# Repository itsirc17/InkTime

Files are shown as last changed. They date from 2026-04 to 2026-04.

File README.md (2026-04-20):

# InkTime

Designed for optimal energy efficiency, InkTime is a custom e-paper smartwatch project. This document serves as a complete technical reference for the project.

## Block Diagram(Architecture)

```mermaid
graph TD
    %% Central MCU
    MCU[nRF52840 Microcontroller]

    %% Power Subsystem
    USB[USB-C Port] -->|5V VBUS| ESD[ESD Protection USBLC6]
    ESD -->|5V| CHG[BQ25180 LiPo Charger]
    DCDC -->|3.3V System Power| MCU
    DCDC -->|3.3V| SENSORS
    BATT[LiPo Battery] <--> CHG
    BATT <--> FG[MAX17048 Fuel Gauge]
    BATT -->|V_BAT| DCDC[RT6160 Buck-Boost DC/DC]

    %% Interconnects
    MCU <-->|I2C Bus| IMU[BMA421 Accelerometer]
    MCU <-->|I2C Bus| HAP[DRV2605 Haptic Driver]
    MCU <-->|I2C Bus| CHG
    MCU <-->|I2C Bus| FG

    MCU -->|SPI & Control| EPD[E-Paper Display Connector]
    MCU -->|PWM/Trigger| HAP
    HAP -->|Analog| LRA[Haptic Motor]

    %% Inputs
    BTN1[SW_UP] -->|GPIO| MCU
    BTN2[SW_ENT] -->|GPIO| MCU
    BTN3[SW_DN] -->|GPIO| MCU

    %% SWD
    SWD[TC2030-IDC SWD Port] <-->|Programming/Debug| MCU
```

## Functionality

### Power Subsystem & Energy Management

Charging Input: Power is supplied via a 16-pin USB-C connector. The data lines are safeguarded against plug-in transients by a USBLC6-2SC6Y TVS diode array.

Battery Charging (BQ25180): A highly integrated linear charger tailored for small wearables. It features power-path management (allowing the device to run on USB power while charging) and interfaces with the MCU via I2C for dynamic charge current configuration and fault monitoring.

Fuel Gauge (MAX17048): Connected directly to the battery, this IC determines the State-Of-Charge (SOC) using voltage measurements and characterization algorithms. This eliminates the need for a power-wasting current sense resistor, reporting battery percentages cleanly over I2C.

Voltage Regulation (RT6160): Because LiPo voltages fluctuate between 4.2V and 3.0V, this Buck-Boost converter guarantees a stable 3.3V supply. It bucks down when the battery is full and boosts up as it depletes, maximizing the usable battery cycle.

Power Consumption Targets: The system aims for < 10 µA in Deep Sleep (MCU + Sensors suspended + Power ICs quiescent). Active processing consumes roughly 4-6 mA, while a display update will draw 10-15 mA for 2-3 seconds depending on the panel.

### Motion Sensing

IMU (BMA421): A Bosch ultra-low-power accelerometer optimized for wearables. It features a built-in hardware step-counter, allowing the MCU to remain in deep sleep while the sensor actively counts steps. The MCU only wakes periodically to sync the data via I2C.

### User Interface & Output

E-Paper Display (EPD): Interfaces through a standard 24-pin FPC connector. The onboard charge-pump circuit utilizes MBR0530 diodes, inductors, and DMG2305UX switching MOSFETs to generate the high drive voltages (+15V/-15V) needed to manipulate the e-ink microcapsules. The MCU can completely sever power to this circuit to prevent standby leakage.

Haptic Feedback (DRV2605): An I2C-connected haptic driver that contains an internal library of waveforms (clicks, buzzes, ramps). This delivers crisp tactile feedback to ERM or LRA motors without requiring the MCU to generate complex PWM signals.

Physical Inputs: Three tactile buttons (SW_UP, SW_ENT, SW_DN) feature hardware debouncing via 0.1uF capacitors. They utilize internal pull-ups and trigger MCU interrupts to wake the system from sleep.

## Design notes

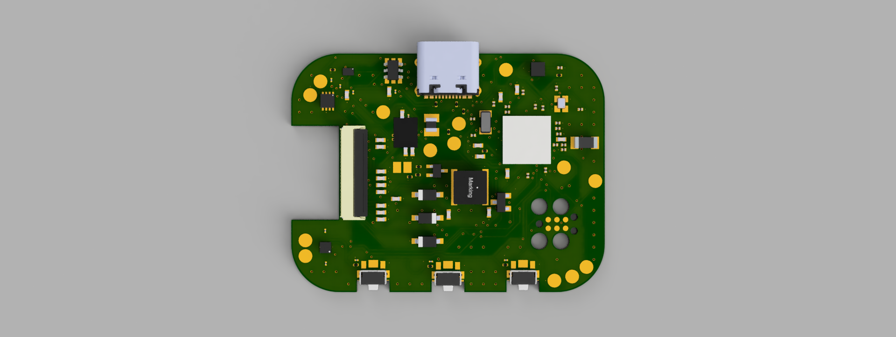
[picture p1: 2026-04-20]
Images/pcb.png

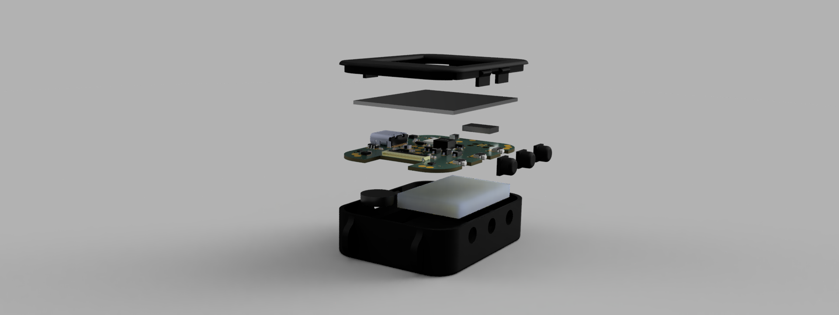
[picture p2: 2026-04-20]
Images/exploded.png

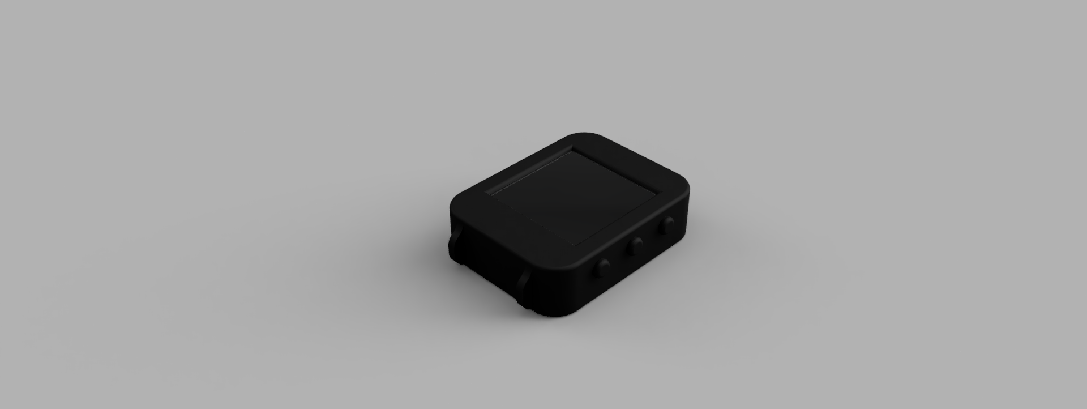
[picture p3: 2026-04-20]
Images/Case.png

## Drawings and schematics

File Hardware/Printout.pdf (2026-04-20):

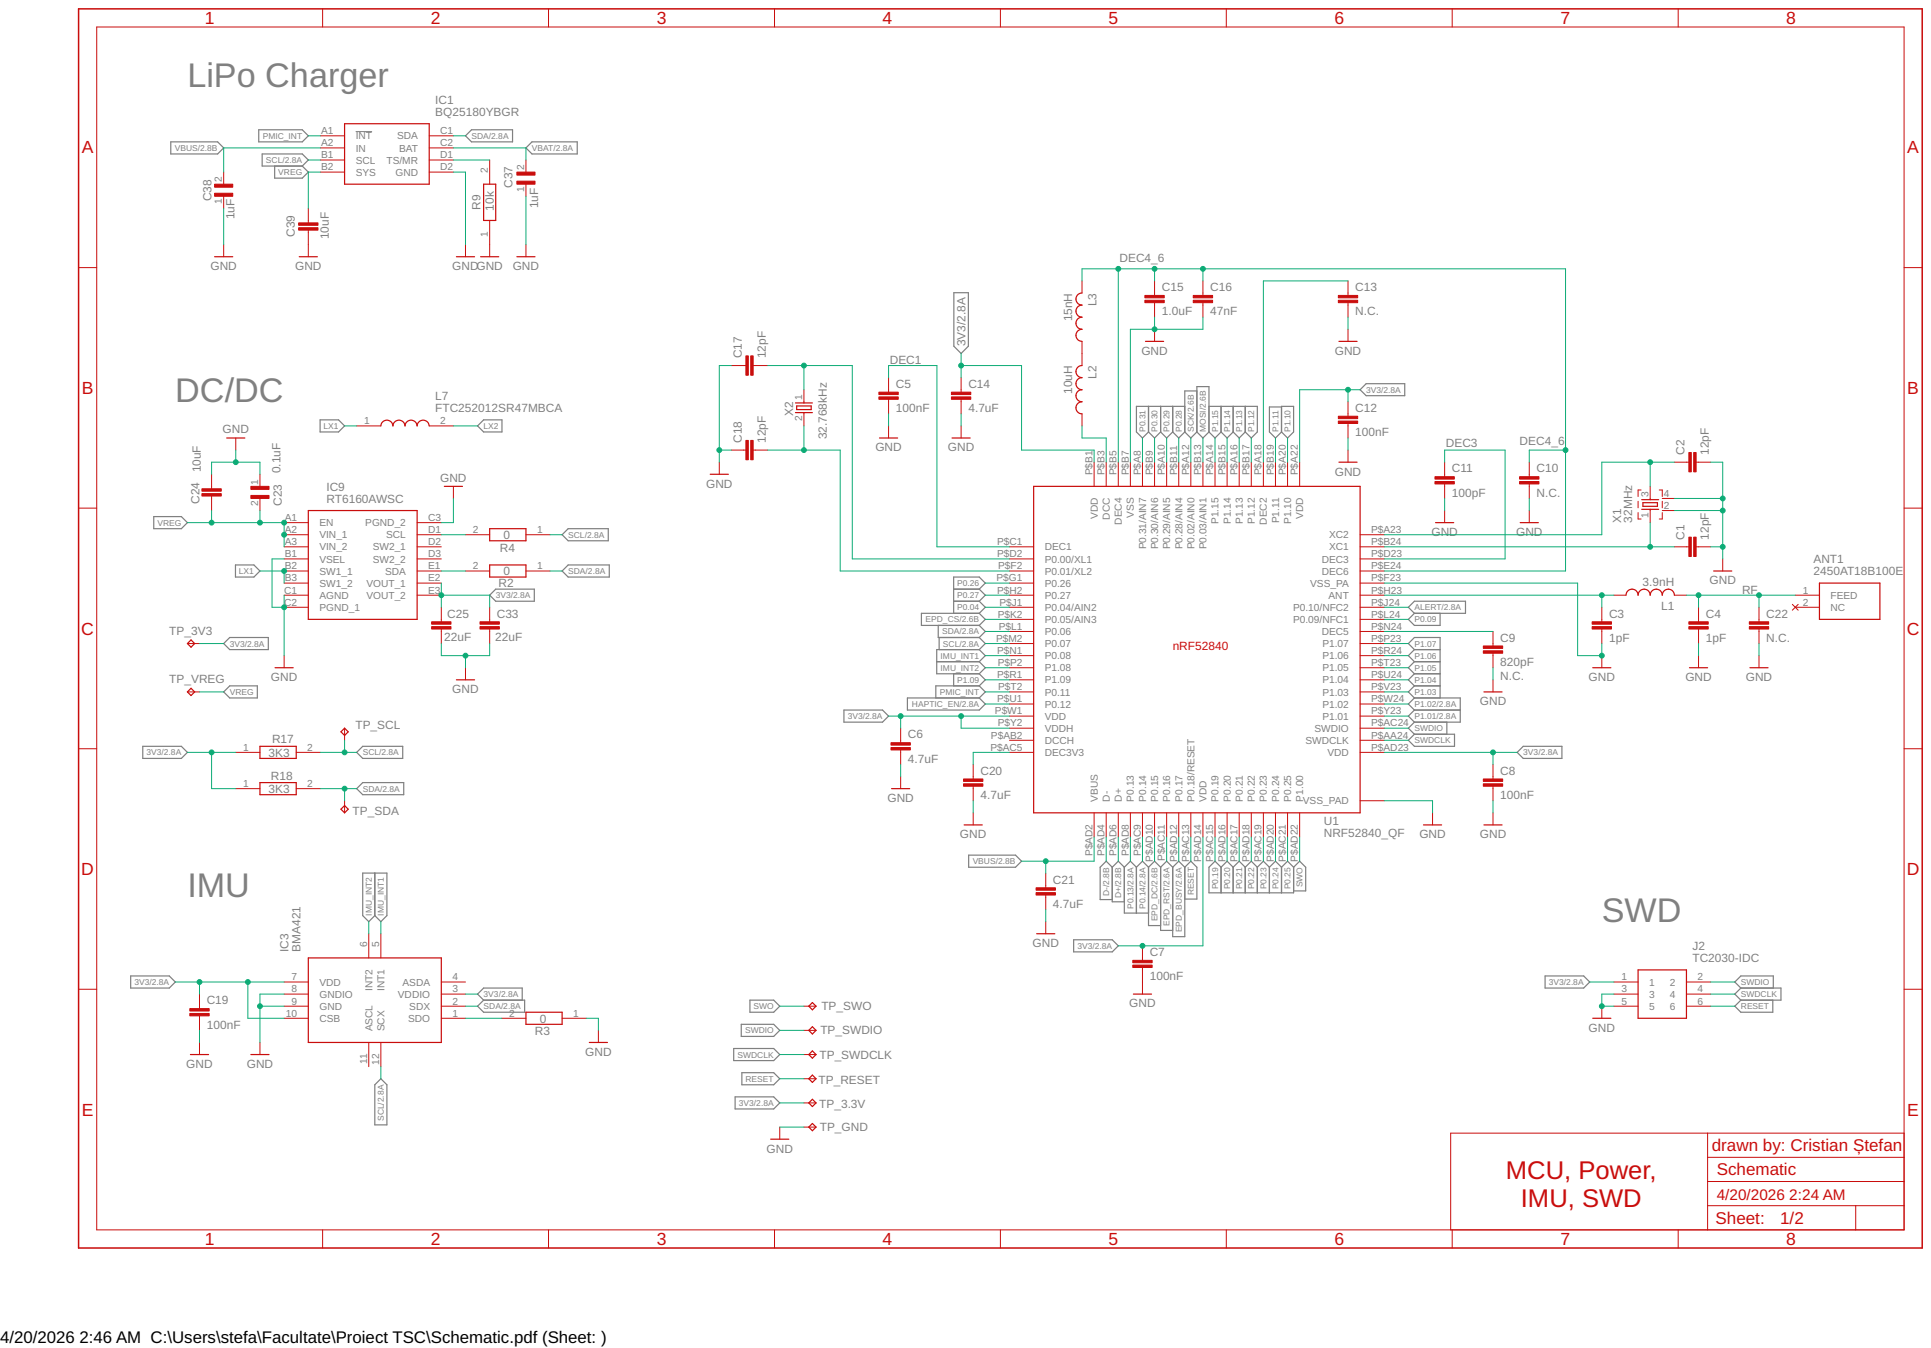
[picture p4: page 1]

4/20/2026 2:46 AM C:\Users\stefa\Facultate\Proiect TSC\Schematic.pdf (Sheet: )

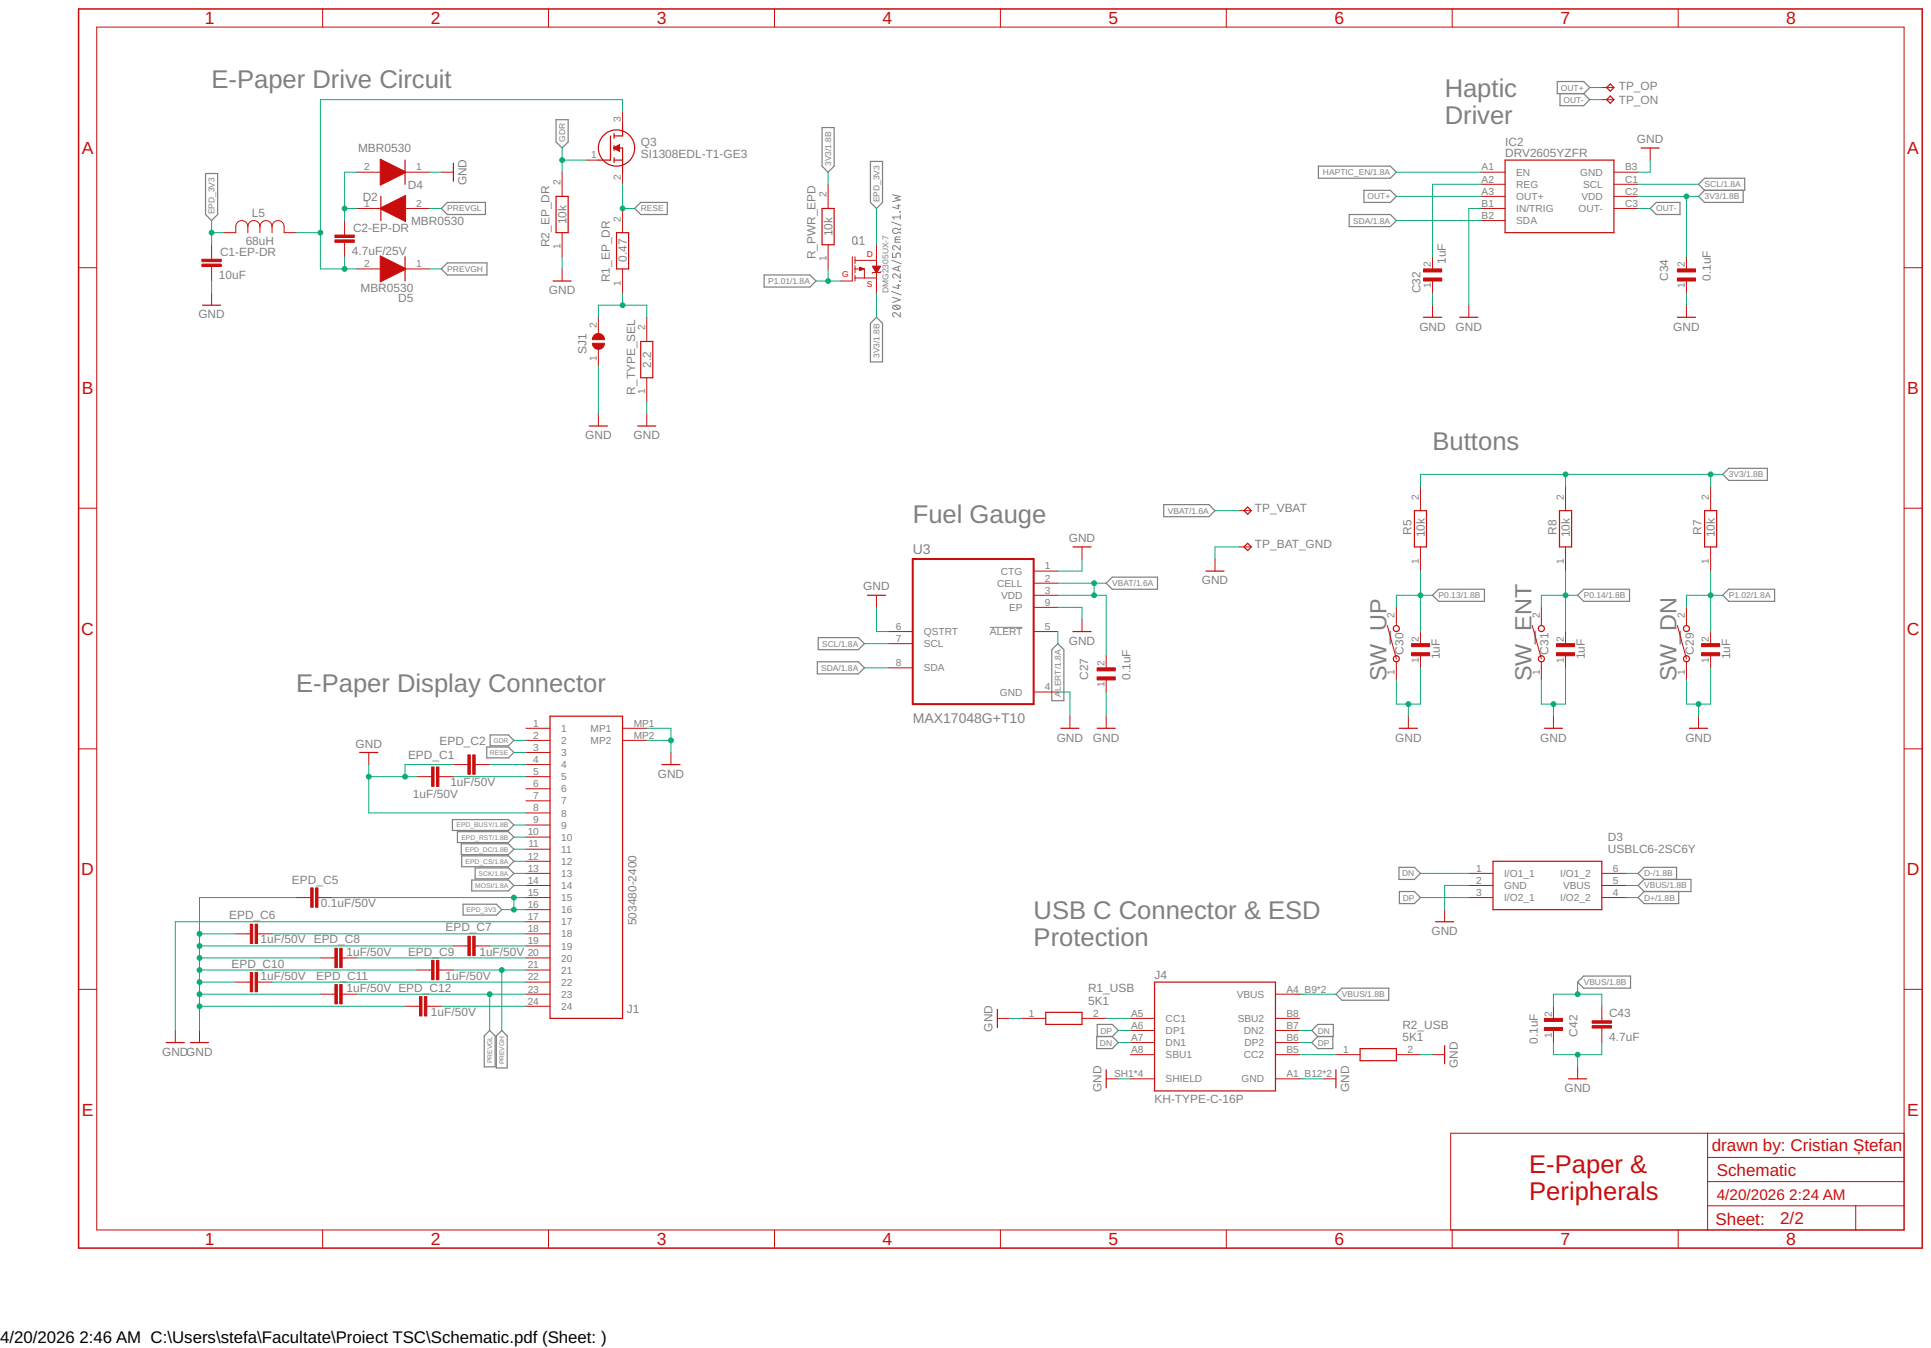
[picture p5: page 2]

EPD_C7 18

1uF/50V EPD_C8 | 19

1uF/50V EPD_C9 | 1uF/50V 20

EPD_C10 | | 21
1uF/50V EPD_C11 | 1uF/50V | 22

4/20/2026 2:46 AM C:\Users\stefa\Facultate\Proiect TSC\Schematic.pdf (Sheet: )

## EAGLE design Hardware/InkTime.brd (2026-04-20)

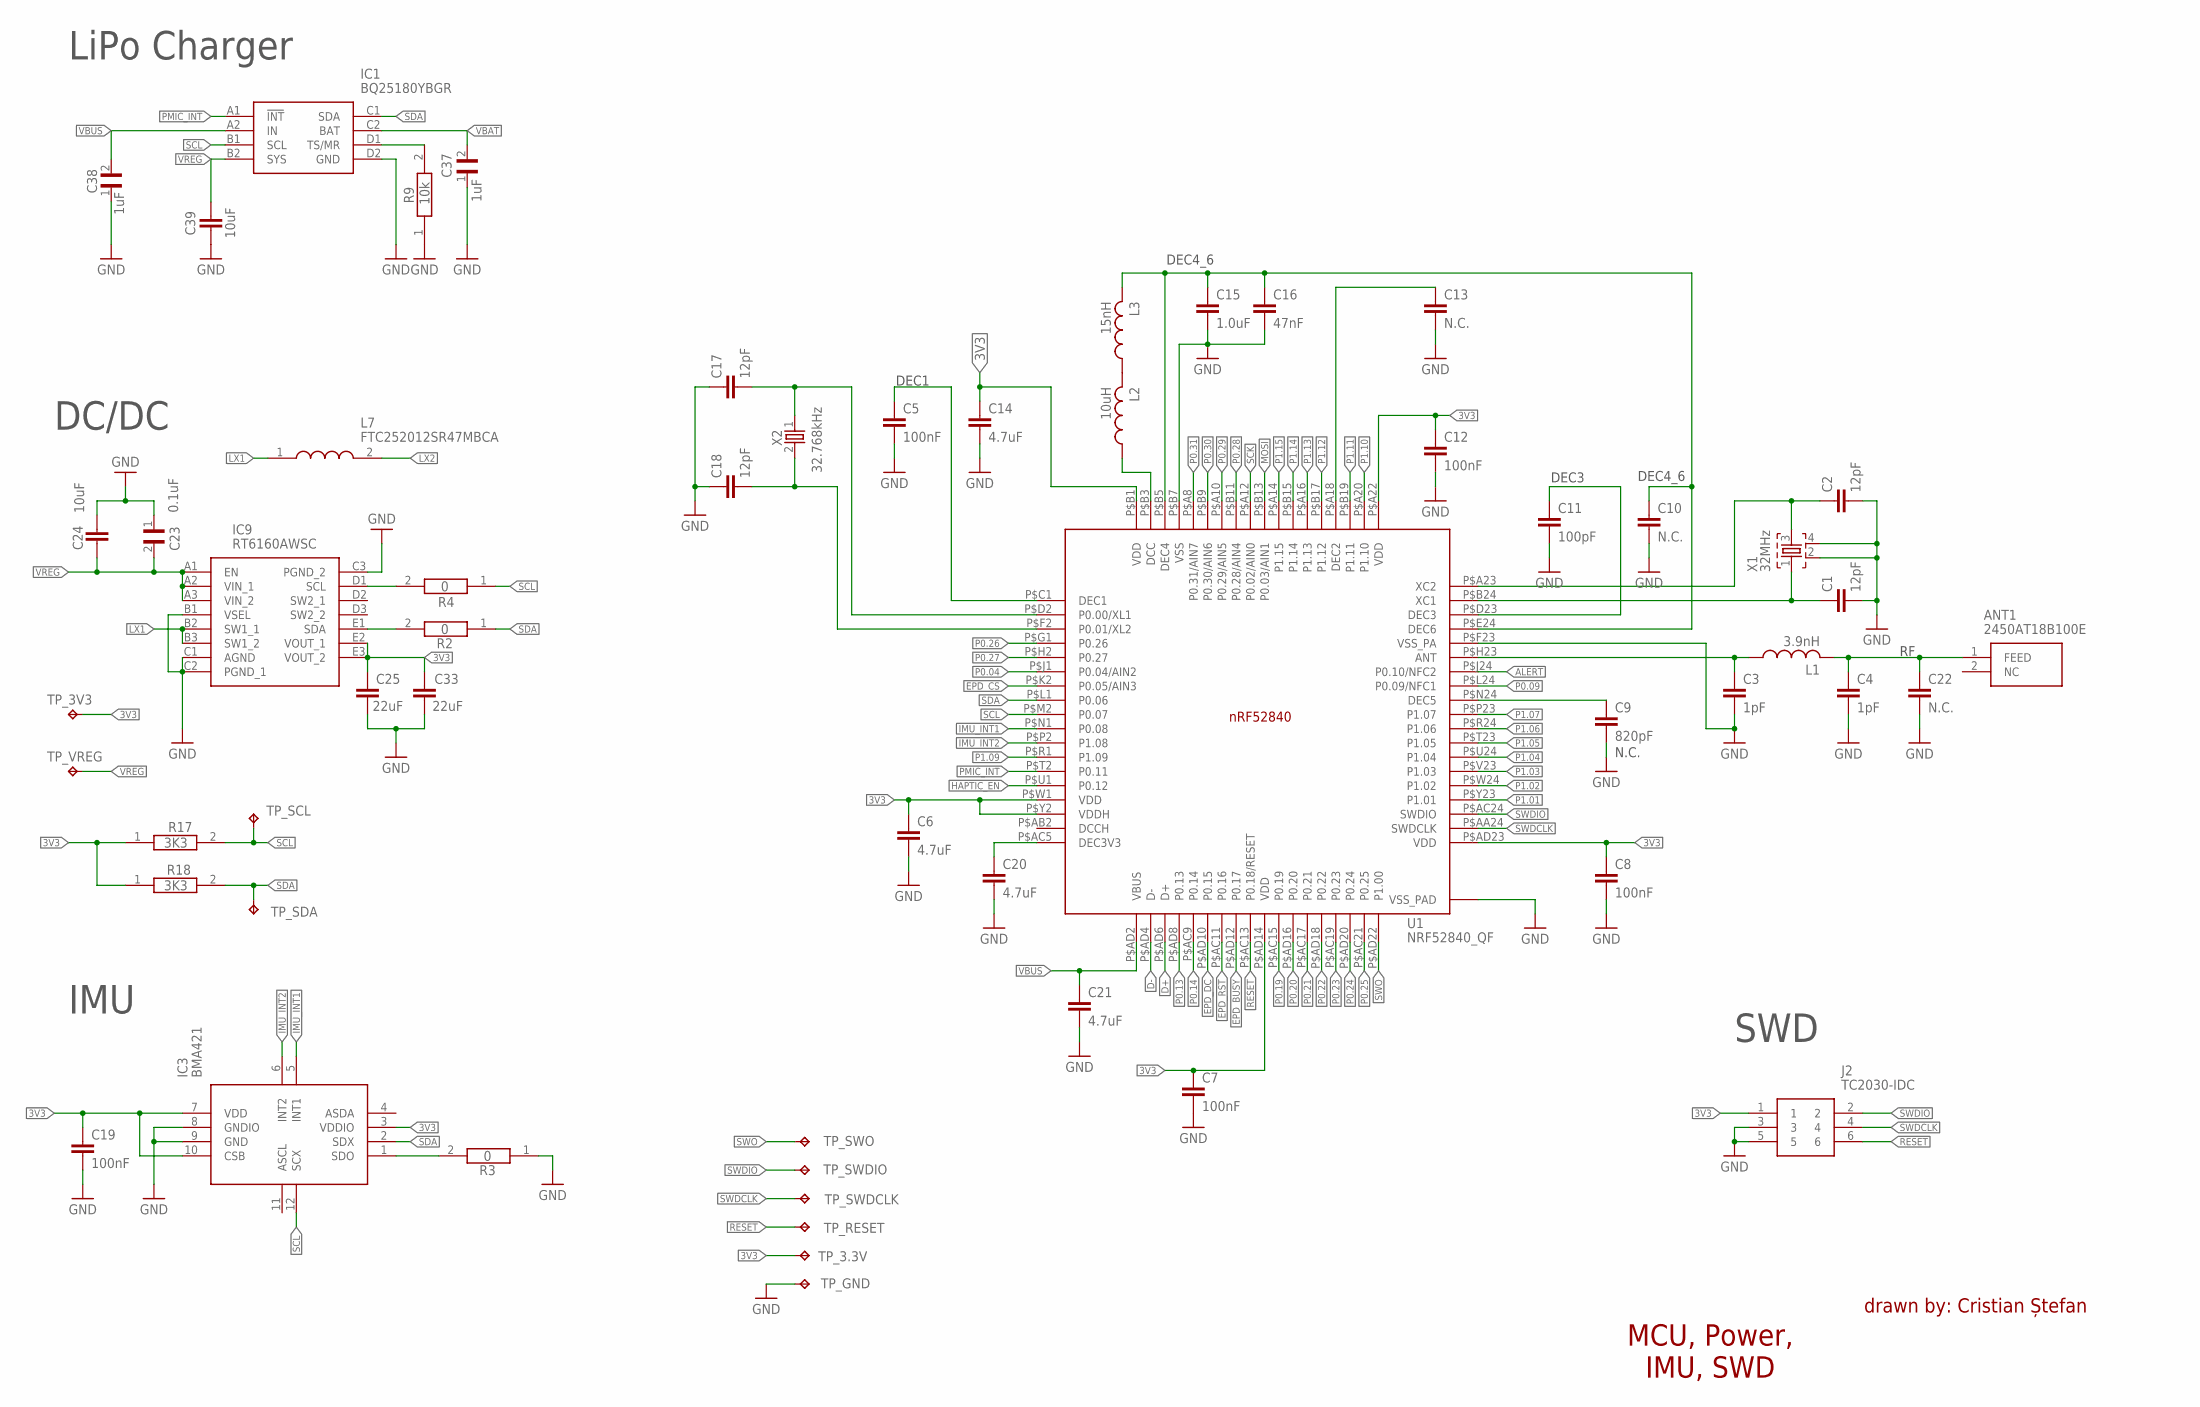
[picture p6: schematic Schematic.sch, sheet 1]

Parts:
ANT1: 2450AT18B100E; 2450AT18B100E_ANTC3216X140N
C1, C2, C17, C18: 12pF; NORDIC_NRF_3_RESC0201_L
C3, C4: 1pF; NORDIC_NRF_3_RESC0201_L
C5, C7, C8, C12, C19: 100nF; NORDIC_NRF_3_RESC0201_L
C6, C14, C20, C21: 4.7uF; NORDIC_NRF_3_RESC0402_L
C9: 820pF; NORDIC_NRF_3_RESC0201_L
C10, C13, C22: N.C.; NORDIC_NRF_3_RESC0201_L
C11: 100pF; NORDIC_NRF_3_RESC0201_L
C15: 1.0uF; NORDIC_NRF_3_RESC0402_L
C16: 47nF; NORDIC_NRF_3_RESC0201_L
C23: 0.1uF; GRM011R60J152KE01L_2_CAPC0201X13N
C24, C39: 10uF; NORDIC_NRF_3_RESC0402_L
C25, C33: 22uF; NORDIC_NRF_3_RESC0402_L
C37, C38: 1uF; GRM011R60J152KE01L_2_CAPC0201X13N
IC1: BQ25180YBGR; BQ25180YBGR_BGA8C40P2X4_100X155X50
IC3: BMA421; BMA423_BMA423
IC9: RT6160AWSC; RT6160AWSC_BGA15C40P3X5_140X230X60
J2: TC2030-IDC; TC2030-IDC_TC2030IDC
L1: 3.9nH; NORDIC_NRF_2_RESC0402_L
L2: 10uH; NORDIC_NRF_2_RESC0201_L
L3: 15nH; NORDIC_NRF_2_RESC0201_L
L7: FTC252012SR47MBCA; MLP2016SR47MT0S1_INDC2016X100N
R2, R3, R4: 0; CPF0201D7K68C1_0201
R9: 10k; CPF0201D7K68C1_0201
R17, R18: 3K3; CPF0201D7K68C1_0201
TP_3.3V, TP_3V3: HECTOR_WATCH_1_TPTP20R; HECTOR_WATCH_1_TP20R
TP_GND: HECTOR_WATCH_1_TPTP20R; HECTOR_WATCH_1_TP20R
TP_RESET: HECTOR_WATCH_1_TPTP20R; HECTOR_WATCH_1_TP20R
TP_SCL: HECTOR_WATCH_1_TPTP20R; HECTOR_WATCH_1_TP20R
TP_SDA: HECTOR_WATCH_1_TPTP20R; HECTOR_WATCH_1_TP20R
TP_SWDCLK: HECTOR_WATCH_1_TPTP20R; HECTOR_WATCH_1_TP20R
TP_SWDIO: HECTOR_WATCH_1_TPTP20R; HECTOR_WATCH_1_TP20R
TP_SWO: HECTOR_WATCH_1_TPTP20R; HECTOR_WATCH_1_TP20R
TP_VREG: HECTOR_WATCH_1_TPTP20R; HECTOR_WATCH_1_TP20R
U1: NRF52840_QF; NORDIC_NRF_4_AQFN50P700X700X85_HS-74N
X1: 32MHz; NORDIC_NRF_BT-XTAL_2016_N
X2: 32.768kHz; NORDIC_NRF_1_XTAL_3215_N

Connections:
3V3: C6.1, C7.1, C8.1, C12.1, C14.1, C19.1, C25.2, C33.2, IC3.3 (VDDIO), IC3.7 (VDD), IC3.10 (CSB), IC9.E2 (VOUT_1), IC9.E3 (VOUT_2), J2.1, R17.1, R18.1, TP_3.3V.TP, TP_3V3.TP, U1.P$A22 (VDD), U1.P$AD14 (VDD), U1.P$AD23 (VDD), U1.P$B1 (VDD), U1.P$W1 (VDD), U1.P$Y2 (VDDH); also elsewhere on the board
ALERT: U1.P$J24 (P0.10/NFC2); also elsewhere on the board
CACA: C5.1, U1.P$C1 (DEC1)
CACA2: C13.1, U1.P$A18 (DEC2)
D+: U1.P$AD6 (D+); also elsewhere on the board
D-: U1.P$AD4 (D-); also elsewhere on the board
EPD_BUSY: U1.P$AD12 (P0.17); also elsewhere on the board
EPD_CS: U1.P$K2 (P0.05/AIN3); also elsewhere on the board
EPD_DC: U1.P$AD10 (P0.15); also elsewhere on the board
EPD_RST: U1.P$AC11 (P0.16); also elsewhere on the board
GND: C1.2, C2.2, C3.2, C4.2, C5.2, C6.2, C7.2, C8.2, C9.2, C10.2, C11.2, C12.2, C13.2, C14.2, C15.2, C16.2, C17.1, C18.1, C19.2, C20.2, C21.2, C22.2, C23.1, C24.1, C25.1, C33.1, C37.1, C38.1, C39.2, IC1.D2 (GND), IC3.8 (GNDIO), IC3.9 (GND), IC9.B1 (VSEL), IC9.C1 (AGND), IC9.C2 (PGND_1), IC9.C3 (PGND_2), J2.3, J2.5, R3.1, R9.1, TP_GND.TP, U1.P$74 (VSS_PAD), U1.P$75 (VSS_PAD), U1.P$76 (VSS_PAD), U1.P$77 (VSS_PAD), U1.P$78 (VSS_PAD), U1.P$79 (VSS_PAD), U1.P$80 (VSS_PAD), U1.P$81 (VSS_PAD), U1.P$82 (VSS_PAD), U1.P$83 (VSS_PAD), U1.P$84 (VSS_PAD), U1.P$85 (VSS_PAD), U1.P$86 (VSS_PAD), U1.P$87 (VSS_PAD), U1.P$88 (VSS_PAD), U1.P$89 (VSS_PAD), U1.P$90 (VSS_PAD), U1.P$B7 (VSS), U1.P$F23 (VSS_PA), X1.2, X1.4; also elsewhere on the board
HAPTIC_EN: U1.P$U1 (P0.12); also elsewhere on the board
IMU_INT1: IC3.5 (INT1), U1.P$N1 (P0.08)
IMU_INT2: IC3.6 (INT2), U1.P$P2 (P1.08)
LX1: IC9.B2 (SW1_1), IC9.B3 (SW1_2), L7.1
LX2: L7.2
MOSI: U1.P$B13 (P0.03/AIN1); also elsewhere on the board
unnamed: IC9.E1 (SDA), R2.2
unnamed: IC9.D1 (SCL), R4.2
unnamed: IC3.1 (SDO), R3.2
unnamed: C20.1, U1.P$AC5 (DEC3V3)
unnamed: C9.1, U1.P$N24 (DEC5)
unnamed: C3.1, L1.1, U1.P$H23 (ANT)
unnamed: C2.1, U1.P$A23 (XC2), X1.3
unnamed: ANT1.1 (FEED), C4.1, C22.1, L1.2
unnamed: C11.1, U1.P$D23 (DEC3)
unnamed: IC1.D1 (TS/MR), R9.2
unnamed: L2.2, L3.1
unnamed: C1.1, U1.P$B24 (XC1), X1.1
unnamed: C17.2, U1.P$D2 (P0.00/XL1), X2.1
unnamed: L2.1, U1.P$B3 (DCC)
unnamed: C10.1, C15.1, C16.1, L3.2, U1.P$B5 (DEC4), U1.P$E24 (DEC6)
unnamed: C18.2, U1.P$F2 (P0.01/XL2), X2.2
P0.04: U1.P$J1 (P0.04/AIN2)
P0.09: U1.P$L24 (P0.09/NFC1)
P0.13: U1.P$AD8 (P0.13); also elsewhere on the board
P0.14: U1.P$AC9 (P0.14); also elsewhere on the board
P0.19: U1.P$AC15 (P0.19)
P0.20: U1.P$AD16 (P0.20)
P0.21: U1.P$AC17 (P0.21)
P0.22: U1.P$AD18 (P0.22)
P0.23: U1.P$AC19 (P0.23)
P0.24: U1.P$AD20 (P0.24)
P0.25: U1.P$AC21 (P0.25)
P0.26: U1.P$G1 (P0.26)
P0.27: U1.P$H2 (P0.27)
P0.28: U1.P$B11 (P0.28/AIN4)
P0.29: U1.P$A10 (P0.29/AIN5)
P0.30: U1.P$B9 (P0.30/AIN6)
P0.31: U1.P$A8 (P0.31/AIN7)
P1.01: U1.P$Y23 (P1.01); also elsewhere on the board
P1.02: U1.P$W24 (P1.02); also elsewhere on the board
P1.03: U1.P$V23 (P1.03)
P1.04: U1.P$U24 (P1.04)
P1.05: U1.P$T23 (P1.05)
P1.06: U1.P$R24 (P1.06)
P1.07: U1.P$P23 (P1.07)
P1.09: U1.P$R1 (P1.09)
P1.10: U1.P$A20 (P1.10)
P1.11: U1.P$B19 (P1.11)
P1.12: U1.P$B17 (P1.12)
P1.13: U1.P$A16 (P1.13)
P1.14: U1.P$B15 (P1.14)
P1.15: U1.P$A14 (P1.15)
PMIC_INT: IC1.A1 (!INT), U1.P$T2 (P0.11)
RESET: J2.6, TP_RESET.TP, U1.P$AC13 (P0.18/RESET)
SCK: U1.P$A12 (P0.02/AIN0); also elsewhere on the board
SCL: IC1.B1 (SCL), IC3.12 (SCX), R4.1, R17.2, TP_SCL.TP, U1.P$M2 (P0.07); also elsewhere on the board
SDA: IC1.C1 (SDA), IC3.2 (SDX), R2.1, R18.2, TP_SDA.TP, U1.P$L1 (P0.06); also elsewhere on the board
SWDCLK: J2.4, TP_SWDCLK.TP, U1.P$AA24 (SWDCLK)
SWDIO: J2.2, TP_SWDIO.TP, U1.P$AC24 (SWDIO)
SWO: TP_SWO.TP, U1.P$AD22 (P1.00)
VBAT: C37.2, IC1.C2 (BAT); also elsewhere on the board
VBUS: C21.1, C38.2, IC1.A2 (IN), U1.P$AD2 (VBUS); also elsewhere on the board
VREG: C23.2, C24.2, C39.1, IC1.B2 (SYS), IC9.A1 (EN), IC9.A2 (VIN_1), IC9.A3 (VIN_2), TP_VREG.TP

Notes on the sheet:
LiPo Charger
N.C.
DEC4_6
DEC3
DEC1
DC/DC
IMU
SWD
drawn by: Cristian Ștefan
MCU, Power, IMU, SWD

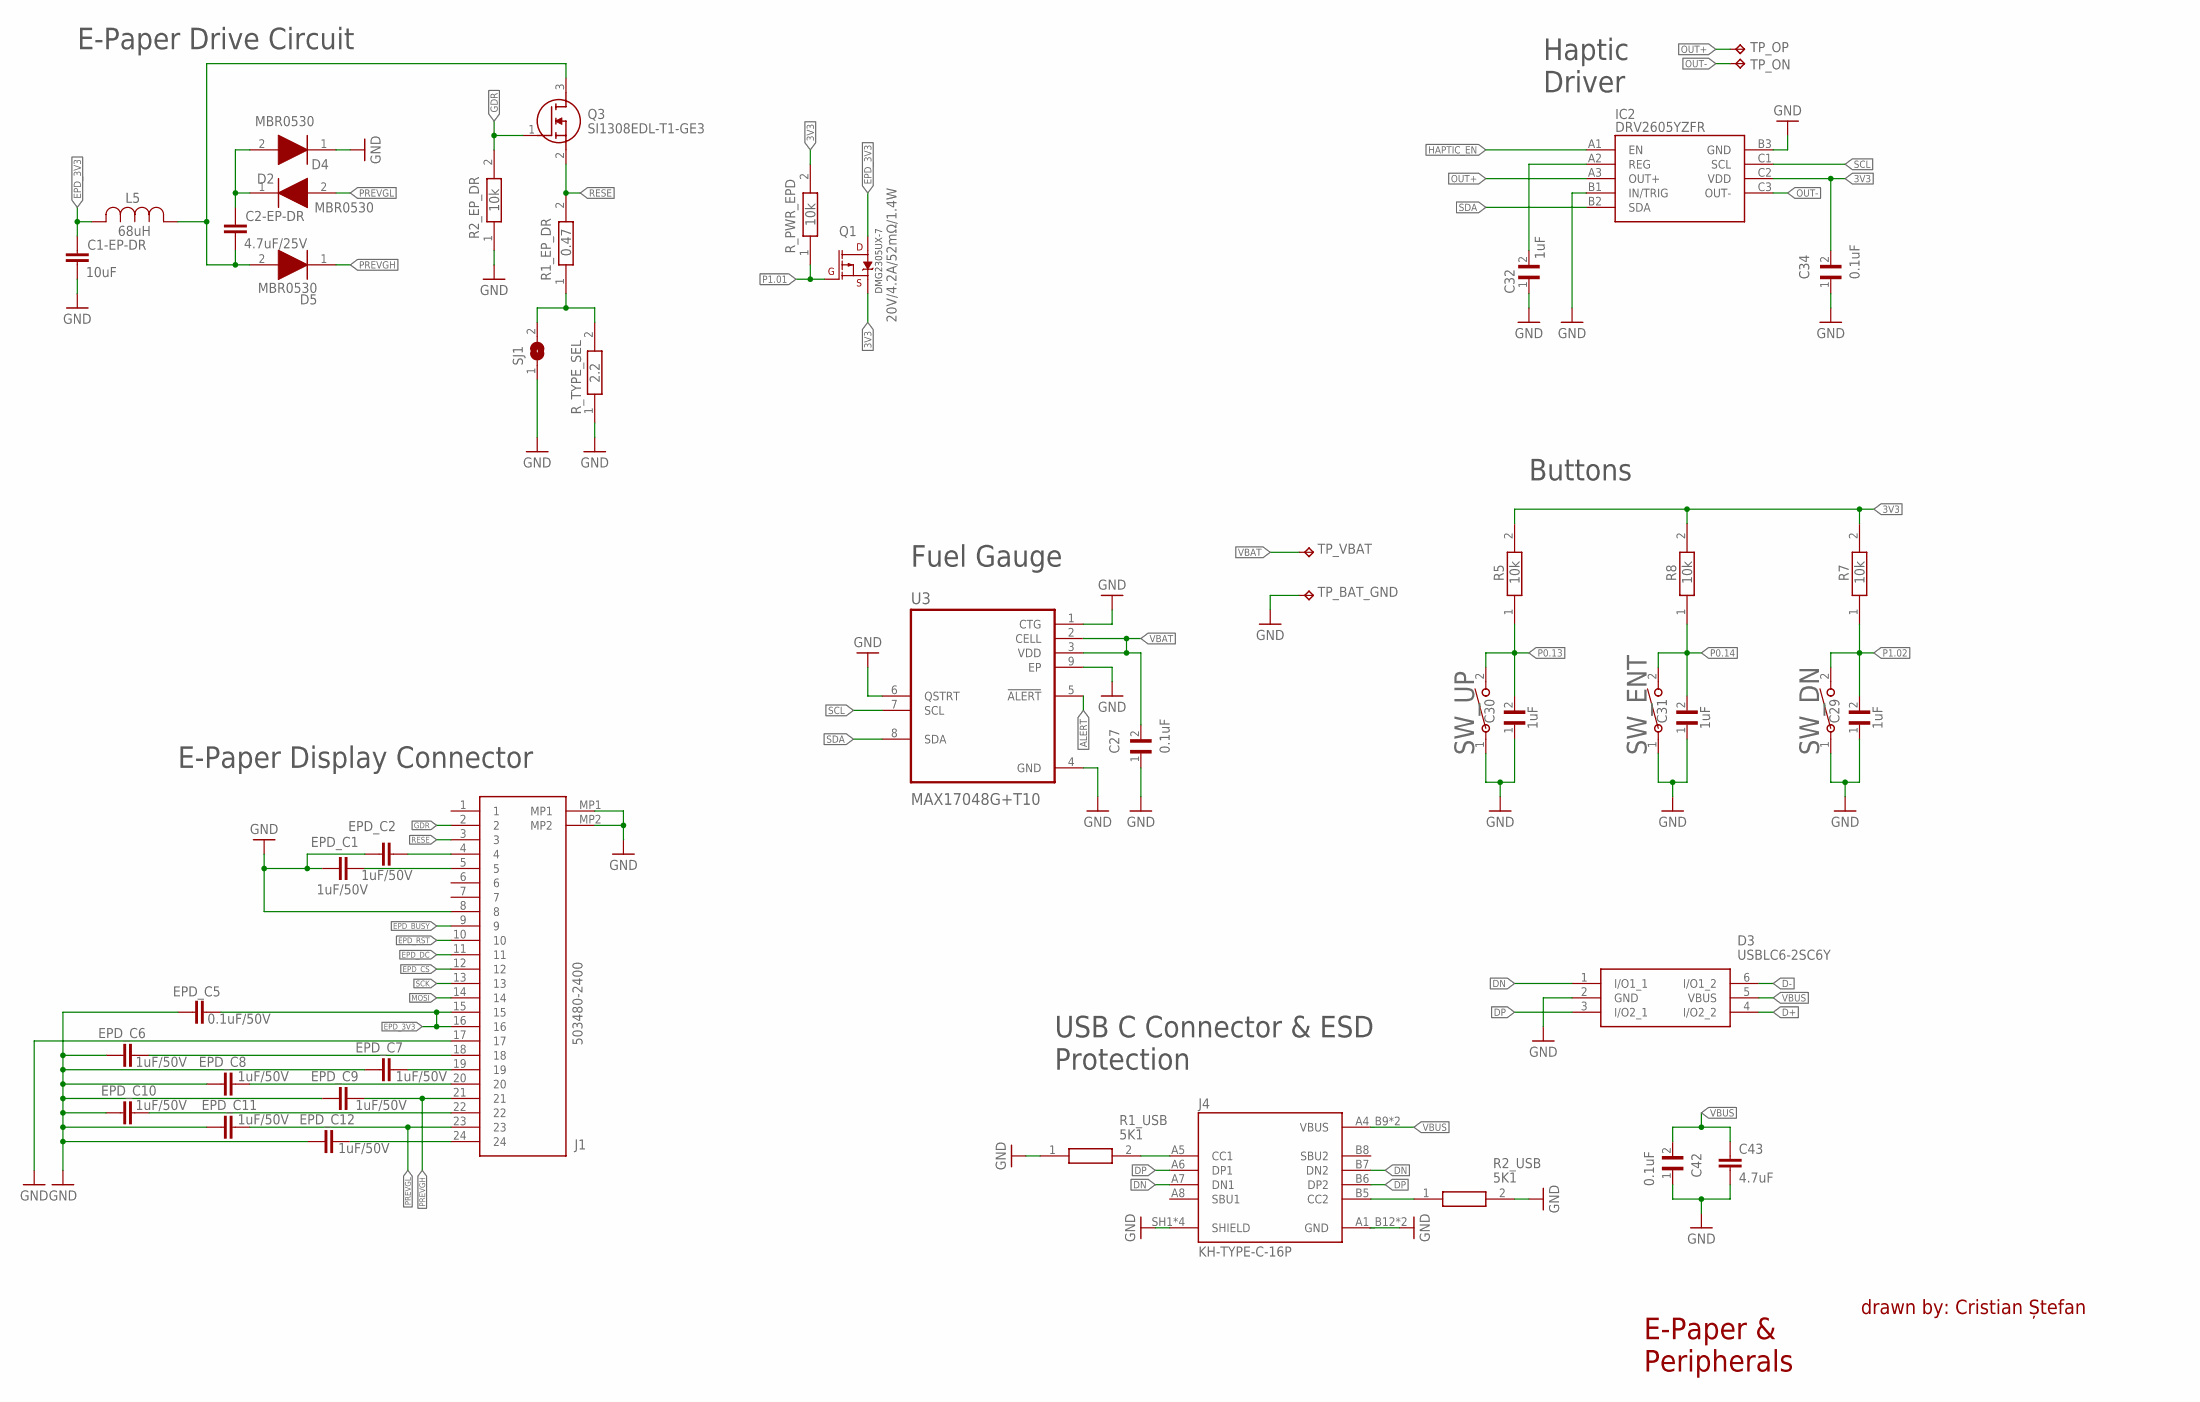
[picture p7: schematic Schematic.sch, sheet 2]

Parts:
C1-EP-DR: 10uF; NORDIC_NRF_3_RESC0402_L
C2-EP-DR: 4.7uF/25V; NORDIC_NRF_3_RESC0402_L
C27, C34, C42: 0.1uF; GRM011R60J152KE01L_2_CAPC0201X13N
C29, C30, C31, C32: 1uF; GRM011R60J152KE01L_2_CAPC0201X13N
C43: 4.7uF; NORDIC_NRF_3_RESC0402_L
D2, D4, D5: MBR0530; ESP32_C6_LIBRARY_5_SOD3716X135N
D3: USBLC6-2SC6Y; ESP32_C6_LIBRARY_3_SOT95P280X145-6N
EPD_C1, EPD_C2, EPD_C6, EPD_C7, EPD_C8, EPD_C9, EPD_C10, EPD_C11, EPD_C12: 1uF/50V; NORDIC_NRF_3_RESC0402_L
EPD_C5: 0.1uF/50V; NORDIC_NRF_3_RESC0402_L
IC2: DRV2605YZFR; DRV2605YZFR_BGA9C50P3X3_144X144X62
J1: 503480-2400; 503480-2400_5034802400
J4: KH-TYPE-C-16P; KH-TYPE-C-16P_KINGHELM_KH-TYPE-C-16P
L5: 68uH; ESP32_C6_LIBRARY_2_IND_4828-WE-TPC_WRE
Q1: 20V/4.2A/52mΩ/1.4W; ESP32_C6_LIBRARY_4_ESP32_C6_LIBRARY_4_ESP32_C6_LIBRARY_4_ES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
Q3: SI1308EDL-T1-GE3; ESP32_C6_LIBRARY_6_SOT65P210X110-3N
R1_EP_DR: 0.47; CPF0201D7K68C1_0201
R1_USB, R2_USB: 5K1; CPF0201D7K68C1_0201
R2_EP_DR, R5, R7, R8: 10k; CPF0201D7K68C1_0201
R_PWR_EPD: 10k; CPF0201D7K68C1_0201
R_TYPE_SEL: 2.2; CPF0201D7K68C1_0201
SJ1: ESP32_C6_LIBRARY_7_JUMPER_SJ
SW_DN: 2025-10-22_07-23-44_LIBRARY_EVP-AKE31A; 2025-10-22_07-23-44_LIBRARY_SW_EVP-AKE31A_PAN
SW_ENT: 2025-10-22_07-23-44_LIBRARY_EVP-AKE31A; 2025-10-22_07-23-44_LIBRARY_SW_EVP-AKE31A_PAN
SW_UP: 2025-10-22_07-23-44_LIBRARY_EVP-AKE31A; 2025-10-22_07-23-44_LIBRARY_SW_EVP-AKE31A_PAN
TP_BAT_GND: HECTOR_WATCH_1_TPTP20R; HECTOR_WATCH_1_TP20R
TP_ON: HECTOR_WATCH_1_TPTP20R; HECTOR_WATCH_1_TP20R
TP_OP: HECTOR_WATCH_1_TPTP20R; HECTOR_WATCH_1_TP20R
TP_VBAT: HECTOR_WATCH_1_TPTP20R; HECTOR_WATCH_1_TP20R
U3: MAX17048G+T10; ESP32_C6_LIBRARY_SON50P200X200X80-9N

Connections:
3V3: C34.2, IC2.C2 (VDD), Q1.2 (S), R5.2, R7.2, R8.2, R_PWR_EPD.2; also elsewhere on the board
ALERT: U3.5 (!ALERT); also elsewhere on the board
D+: D3.4 (I/O2_2); also elsewhere on the board
D-: D3.6 (I/O1_2); also elsewhere on the board
DN: D3.1 (I/O1_1), J4.A7 (DN1), J4.B7 (DN2)
DP: D3.3 (I/O2_1), J4.A6 (DP1), J4.B6 (DP2)
EPD_3V3: C1-EP-DR.1, EPD_C5.2, J1.15, J1.16, L5.2, Q1.3 (D)
EPD_BUSY: J1.9; also elsewhere on the board
EPD_CS: J1.12; also elsewhere on the board
EPD_DC: J1.11; also elsewhere on the board
EPD_RST: J1.10; also elsewhere on the board
GDR: J1.2, Q3.1 (G), R2_EP_DR.2
GND: C1-EP-DR.2, C27.1, C29.1, C30.1, C31.1, C32.1, C34.1, C42.1, C43.2, D3.2 (GND), D4.1 (K), EPD_C1.1, EPD_C2.1, EPD_C5.1, EPD_C6.1, EPD_C7.1, EPD_C8.1, EPD_C9.1, EPD_C10.1, EPD_C11.1, EPD_C12.1, IC2.B1 (IN/TRIG), IC2.B3 (GND), J1.8, J1.17, J1.MP1, J1.MP2, J4.A1_B12 (GND), J4.A12_B1 (GND), J4.SH1 (SHIELD), J4.SH2 (SHIELD), J4.SH3 (SHIELD), J4.SH4 (SHIELD), R1_USB.1, R2_EP_DR.1, R2_USB.2, R_TYPE_SEL.1, SJ1.1, SW_DN.1, SW_ENT.1, SW_UP.1, TP_BAT_GND.TP, U3.1 (CTG), U3.4 (GND), U3.6 (QSTRT), U3.9 (EP); also elsewhere on the board
HAPTIC_EN: IC2.A1 (EN); also elsewhere on the board
MOSI: J1.14; also elsewhere on the board
unnamed: C2-EP-DR.1, D2.1 (K), D4.2 (A)
unnamed: J4.B5 (CC2), R2_USB.1
unnamed: R1_EP_DR.1, R_TYPE_SEL.2, SJ1.2
unnamed: C2-EP-DR.2, D5.2 (A), L5.1, Q3.3 (D)
unnamed: EPD_C2.2, J1.4
unnamed: C32.2, IC2.A2 (REG)
unnamed: EPD_C1.2, J1.5
unnamed: EPD_C6.2, J1.18
unnamed: EPD_C7.2, J1.19
unnamed: J4.A5 (CC1), R1_USB.2
unnamed: EPD_C8.2, J1.20
unnamed: EPD_C10.2, J1.22
unnamed: EPD_C12.2, J1.24
OUT+: IC2.A3 (OUT+), TP_OP.TP
OUT-: IC2.C3 (OUT-), TP_ON.TP
P0.13: C30.2, R5.1, SW_UP.2; also elsewhere on the board
P0.14: C31.2, R8.1, SW_ENT.2; also elsewhere on the board
P1.01: Q1.1 (G), R_PWR_EPD.1; also elsewhere on the board
P1.02: C29.2, R7.1, SW_DN.2; also elsewhere on the board
PREVGH: D5.1 (K), EPD_C9.2, J1.21
PREVGL: D2.2 (A), EPD_C11.2, J1.23
RESE: J1.3, Q3.2 (S), R1_EP_DR.2
SCK: J1.13; also elsewhere on the board
SCL: IC2.C1 (SCL), U3.7 (SCL); also elsewhere on the board
SDA: IC2.B2 (SDA), U3.8 (SDA); also elsewhere on the board
VBAT: C27.2, TP_VBAT.TP, U3.2 (CELL), U3.3 (VDD); also elsewhere on the board
VBUS: C42.2, C43.1, D3.5 (VBUS), J4.A4_B9 (VBUS), J4.A9_B4 (VBUS); also elsewhere on the board

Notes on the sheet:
DMG2305UX-7
E-Paper Drive Circuit
Haptic Driver
Buttons
Fuel Gauge
USB C Connector & ESD Protection
E-Paper Display Connector
drawn by: Cristian Ștefan
E-Paper & Peripherals

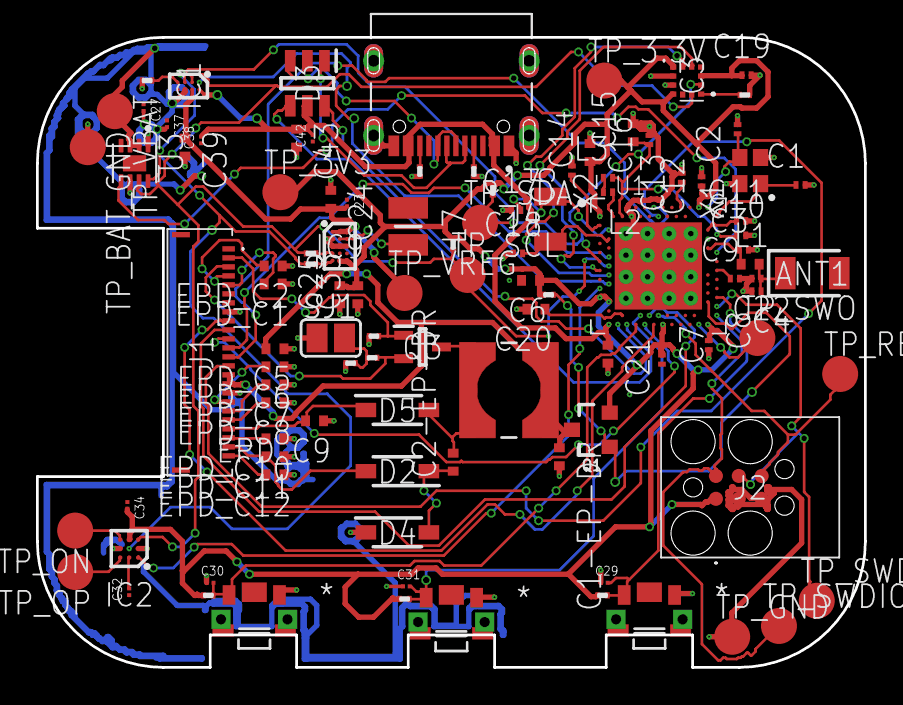
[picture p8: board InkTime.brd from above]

Board: 4 copper layers, 46.0 x 35.0 mm, 105 parts (0 on the bottom side), 69 nets.

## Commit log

2026-04-10 added Hardware Folder
    [InkTime.brd]
2026-04-10 added Schematic.sch
    [Schematic.sch]
2026-04-20 Updated Hardware
    [InkTime.brd, Schematic.sch]

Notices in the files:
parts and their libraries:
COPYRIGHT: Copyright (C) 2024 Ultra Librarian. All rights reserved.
